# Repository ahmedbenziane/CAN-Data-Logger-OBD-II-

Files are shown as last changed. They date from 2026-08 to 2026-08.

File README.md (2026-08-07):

# Automotive CAN Data Logger & OBD-II Scanner

## Overview
Open-source, dual-mode embedded platform for vehicle data acquisition.
Designed for driver-behaviour analysis, fleet telematics, and CAN bus reverse-engineering.
Works with **any** OBD-II compliant vehicle (active polling) and **any** CAN bus (passive sniffing).
Tested and validated on a production Renault Clio IV.

## Features
- **Active OBD-II polling** – retrieves RPM, speed, coolant temperature, throttle position,
  engine load, and intake air temperature in real time
- **Passive CAN sniffing** – captures every frame on the bus in listen-only mode
- **Proprietary signal reverse-engineering** – mapping of steering angle, wheel speeds,
  and brake pressure (verified against vehicle dynamics)
- **Python live sniffer** – terminal dashboard with per-ID frame count, Hz, and raw bytes;
  optional DBC decoding for immediate signal display
- **SD card logging** – raw frames (binary) and decoded CSV for offline analysis
- **Serial-command marker** – insert timestamped markers during a drive for precise
  event correlation
- **Custom 4-layer PCB** – integrates ESP32-S3, MCP2515 CAN controller, GPS, IMU,
  microSD, USB-C, and automotive power protection

## Repository Structure
```text
├── firmware/   # PlatformIO project (ESP-IDF, FreeRTOS)
├── software/   # Python tools: sniffer, decoder, log extractor, validation plots
├── hardware/   # Altium designer files, BOM, Gerber manufacturing files, schematics PDF
├── docs/       # Additional documentation, signal database, application notes
└── README.md
```

## Getting Started

### Hardware
1. Order the PCB from your favourite manufacturer using the Gerber files in `hardware/Gerber/`.
2. Source the components listed in `hardware/BOM.csv`.
3. Assemble the board (all SMD parts are on the top side; through-hole connectors are hand-soldered).

### Firmware
1. Install [PlatformIO](https://platformio.org/).
2. Open the `firmware/` folder as a PlatformIO project.
3. Select the build environment:
   - `node_a` – **real-car OBD-II polling** (normal mode)
   - `node_a` with `PASSIVE_SNIFF_MODE` – **listen-only CAN capture**
   - `node_b` – **bench simulator** (for testing without a vehicle)
4. Build and upload to the ESP32-S3.

### Software
```bash
pip install -r software/requirements.txt
python software/can_sniffer.py --port 
```

Additional Python tools:

- `decode_log.py` – process candump logs and decode frames with a DBC file
- `extract_can.py` – extract pure CAN frames from serial console logs
- `plot_validation.py` – generate validation plots from OBD-II JSON logs

## Validation
The system has been validated on a Real Car:

- Active OBD-II polling matches dashboard gauges within their resolution
- Passive sniffing captures all broadcast CAN identifiers 
- Proprietary signals (steering, wheel speeds, brake pressure) are decoded and physically verified
- Continuous logging over a 30-minute drive with zero firmware crashes

## Customisation
- Add your own signal definitions by editing  DBC file
- Modify the OBD-II schedule in `decoder_app.c` to poll different PIDs
- Implement on-device inference by deploying a trained model using TensorFlow Lite Micro

## License
This project is released under the MIT License.

## Acknowledgements
- comma-ai/opendbc for open CAN databases
- JLCPCB for PCB fabrication
- The open-source automotive community for reverse-engineering knowledge

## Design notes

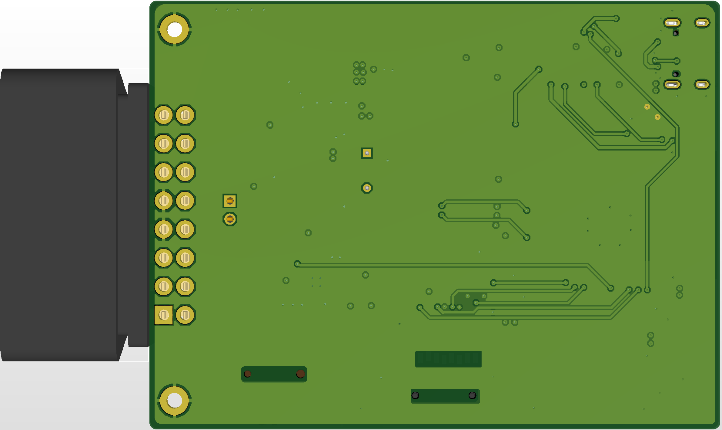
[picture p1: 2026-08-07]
hardware/photos/CAR_Interface_PCB_buttom.png

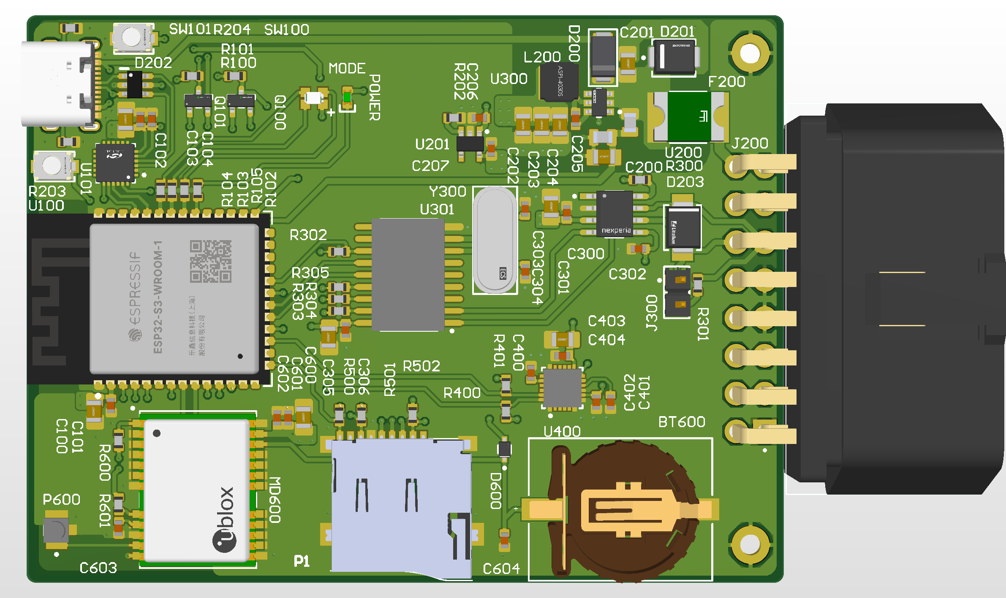
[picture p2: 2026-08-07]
hardware/photos/CAR_Interface_PCB.png

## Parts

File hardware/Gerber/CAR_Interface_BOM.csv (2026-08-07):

Comment | Description | Designator | Footprint | LibRef | Quantity
S8411-45R | BATTERY HOLDER COIN 12MM SMD | BT600 | FP-S8411-45R-MFG | CMP-15817-000007-1 | 1
10u | Capacitor SMD 0805 | C100, C102, C201, C202, C203, C204, C301, C305, C403, C600 | CAP_0805 | CAP_0805 | 10
100n | Capacitor SMD 0603 | C101, C103, C104, C205, C206, C207, C300, C302, C306, C401, C402, C404, C601, C602, C603, C604 | CAP_0603 | CAP_0603 | 16
100n | Capacitor SMD 0805 | C200 | CAP_0805 | CAP_0805 | 1
33pF | Capacitor SMD 0603 | C303, C304 | CAP_0603 | CAP_0603 | 2
2.2nF | Capacitor SMD 0603 | C400 | CAP_0603 | CAP_0603 | 1
D_SCH_SMA | Diode Schottky SMD SMA (DO-214AA) | D200 | DO-214AC-2 (SMA) | D_SCHOTTKY_SMA | 1
SMBJ24A | TVS DIODE 24V 38.9V SMB | D201 | FP-SMBJ-MFG | CMP-07401-000035-1 | 1
USBLC6-2SC6 | Low-Capacitance ESD Protection USB | D202 | SOT-23-6 | USBLC6-2SC6 | 1
P6SMB18CA | TVS DIODE 15.3V 25.5V DO214AA | D203 | FP-P6SMB-CA-MFG | CMP-08607-000095-1 | 1
BAT54J,115 | DIODE SCHOTTKY 30V 200MA SOD323F | D600 | FP-SOD323F-MFG | CMP-14398-000037-1 | 1
2920L050/72GR | PTC RESET FUSE 60V 1.1A 2920 | F200 | FP-2920L-MFG | CMP-08606-000028-1 | 1
C-OBD-II-16M | OBD II 16pin 90 Degree Angle Male Plug Connector | J200 | COMTECH_C-OBD-II-16M | CMP-002-00074-1 | 1
USB4105-GF-A-060 | USB Connector Type C SMT 12 Pin | J201 | USB4105-GF-A-060 | USB4105-GF-A-060 | 1
TSW-102-14-G-S | CONN HEADER VERT 2POS 2.54MM | J300 | FP-TSW-102-14-G-S-MFG | CMP-02766-001740-1 | 1
4.7uH | Power Inductor SMD ASPI-4030S Series | L200 | ASPI-4030S | ASPI-4030S | 1
NEO-M9N-00B | M9 standard precision module | MD600 | FP-NEO-M9N-00B-MFG | CMP-207130-000006-2 | 1
TOGIALED TJ-S2012SW8TWMLCCYRGB-A5 | RGB LED Common Anode SMD Diffused 0805 Top View | MODE | 150080M153000 | 150080M153000 | 1
ST-TF-003A | Micro SD Card Socket | P1 | SUNTECH_ST-TF-003A | CMP-002-00072-2 | 1
U.FL-R-SMT-1(01) | Ultra Small Coaxial Connector, 6 GHz, -40 to 90 degC, 3-Pin SMD, RoHS, Bulk | P600 | HRS-U.FL-R-SMT-3_V | CMP-2000-05153-1 | 1
GREEN | LED 0603 GREEN SMD | POWER | LED_0603_GREEN | LED_0603_GREEN | 1
BSS138 | MOSFET N-CH 50V 220MA SOT-23 | Q100, Q101 | FP-318-08-IPC_B | CMP-07173-000101-1 | 2
10k | Resistor SMD 0603 | R100, R101, R300 | RES_0603 | RES_0603 | 3
620Ohm | Resistor SMD 0603 | R102, R103 | RES_0603 | RES_0603 | 2
360Ohm | Resistor SMD 0603 | R104, R105 | RES_0603 | RES_0603 | 2
100k | Resistor SMD 0805 | R200 | RES_0805 | RES_0805 | 1
10k | Resistor SMD 0805 | R201 | RES_0805 | RES_0805 | 1
5k1 | Resistor SMD 0603 | R202, R203, R204, R302, R303, R304, R305, R400, R401, R500, R501, R502, R600, R601 | RES_0603 | RES_0603 | 14
120Ohm | Resistor SMD 0603 | R301 | RES_0603 | RES_0603 | 1
TL1015AF160QG | SWITCH TACTILE SPST-NO 0.05A 12V | SW100, SW101 | FP-TL1015AF160QG-MFG | CMP-17879-000003-1 | 2
ESP32-S3-WROOM-1-N4 | 2.4 GHz Wi-Fi (802.11 b/g/n) and Bluetooth 5 (LE) Module ESP32-S3, 4MB Flash, on-board PCB antenna) | U100 | ESP32-S3-WROOM-1 | ESP32-S3-WROOM-1-N4 | 1
CP2102N-A02-GQFN24R | IC USB TO UART BRIDGE QFN24 | U101 | FP-CP2102N-A02-GQFN24R-MFG | CMP-08107-000009-2 | 1
AP63205WU-7 | IC REG BUCK 5V 2A TSOT26 | U200 | FP-TSOT26-MFG | CMP-12757-000001-1 | 1
NCP115ASN330T2G | LDO Regulator - High PSRR 300 mA 3.3V TSOP-5 | U201 | TSOT25 | NCP115ASN330T2G | 1
TJA1042T/3/CM,118 | IC TRANSCEIVER HALF 1/1 8SO | U300 | FP-SOT96-1-IPC_A | CMP-10098-000021-1 | 1
MCP2515T-I/SO | Stand-Alone CAN Controller With SPI Interface, 18-Pin SOIC, Industrial Temperature, Tape and Reel | U301 | SOIC-SO18_N | CMP-0186-00139-2 | 1
MPU-6050 | 3-Axis Gyroscope, Accelerometer and a Digital Motion Processor(TM) (DMP), 2.375 to 3.46 V, -40 to 85 degC, 24-Pin QFN, RoHS, Tape and Reel | U400 | IS-QFN-24_V | CMP-1753-00002-2 | 1
ECS-80-20-4X |  | Y300 | FP-ECS-80-20-4X-MFG | CMP-1669-00002-3 | 1

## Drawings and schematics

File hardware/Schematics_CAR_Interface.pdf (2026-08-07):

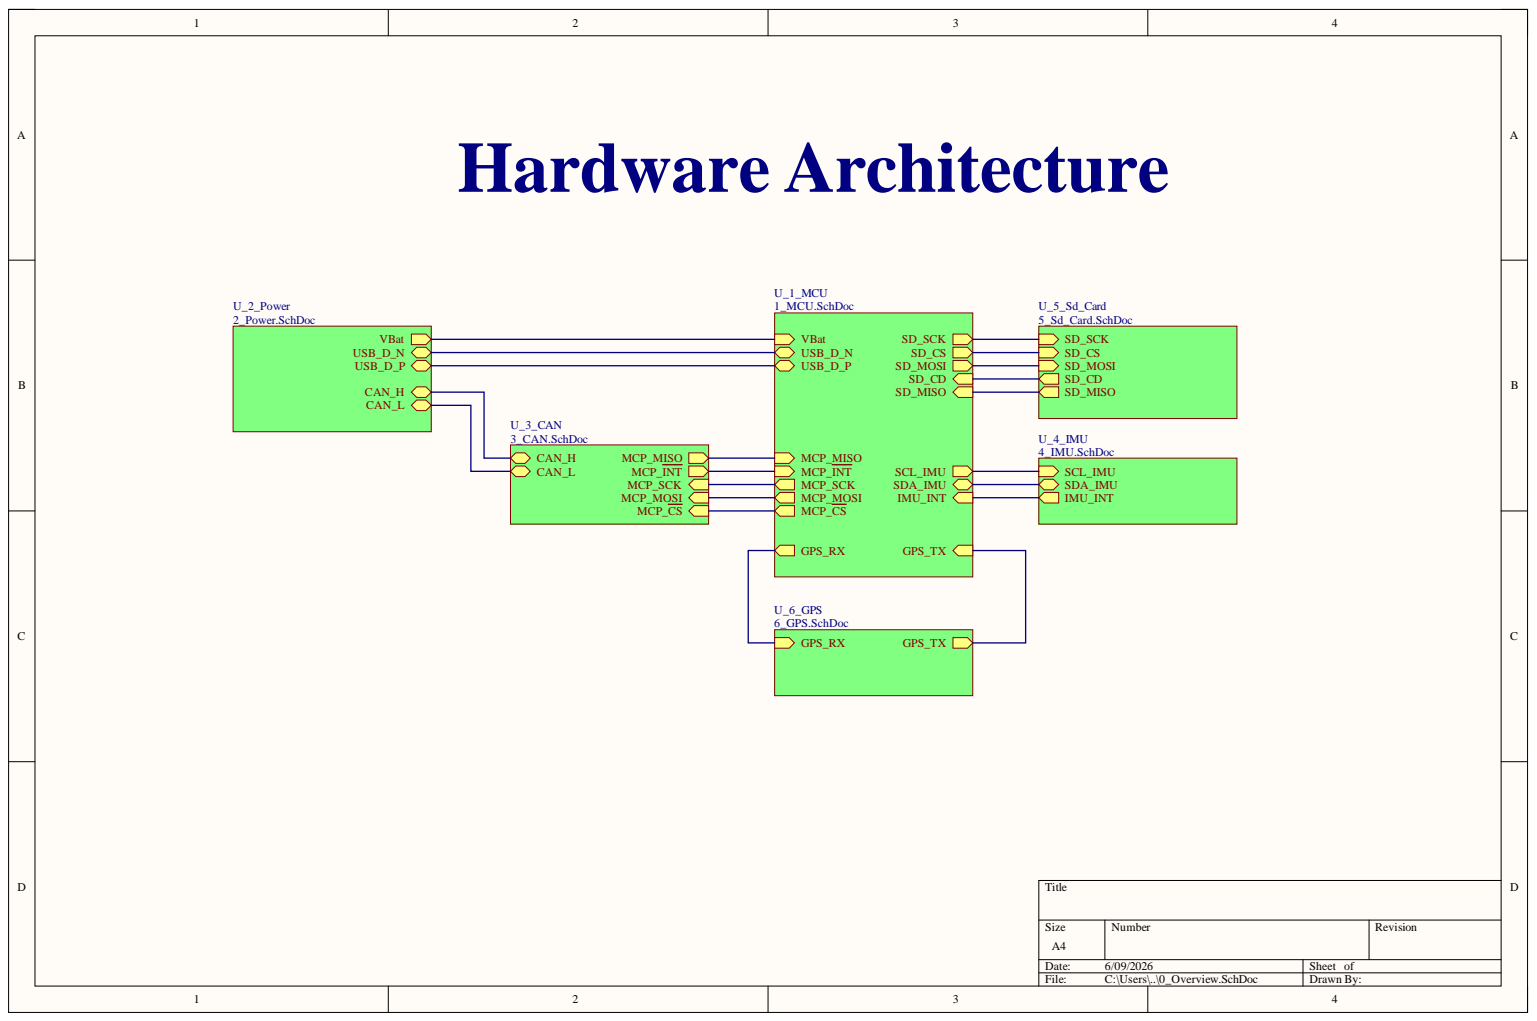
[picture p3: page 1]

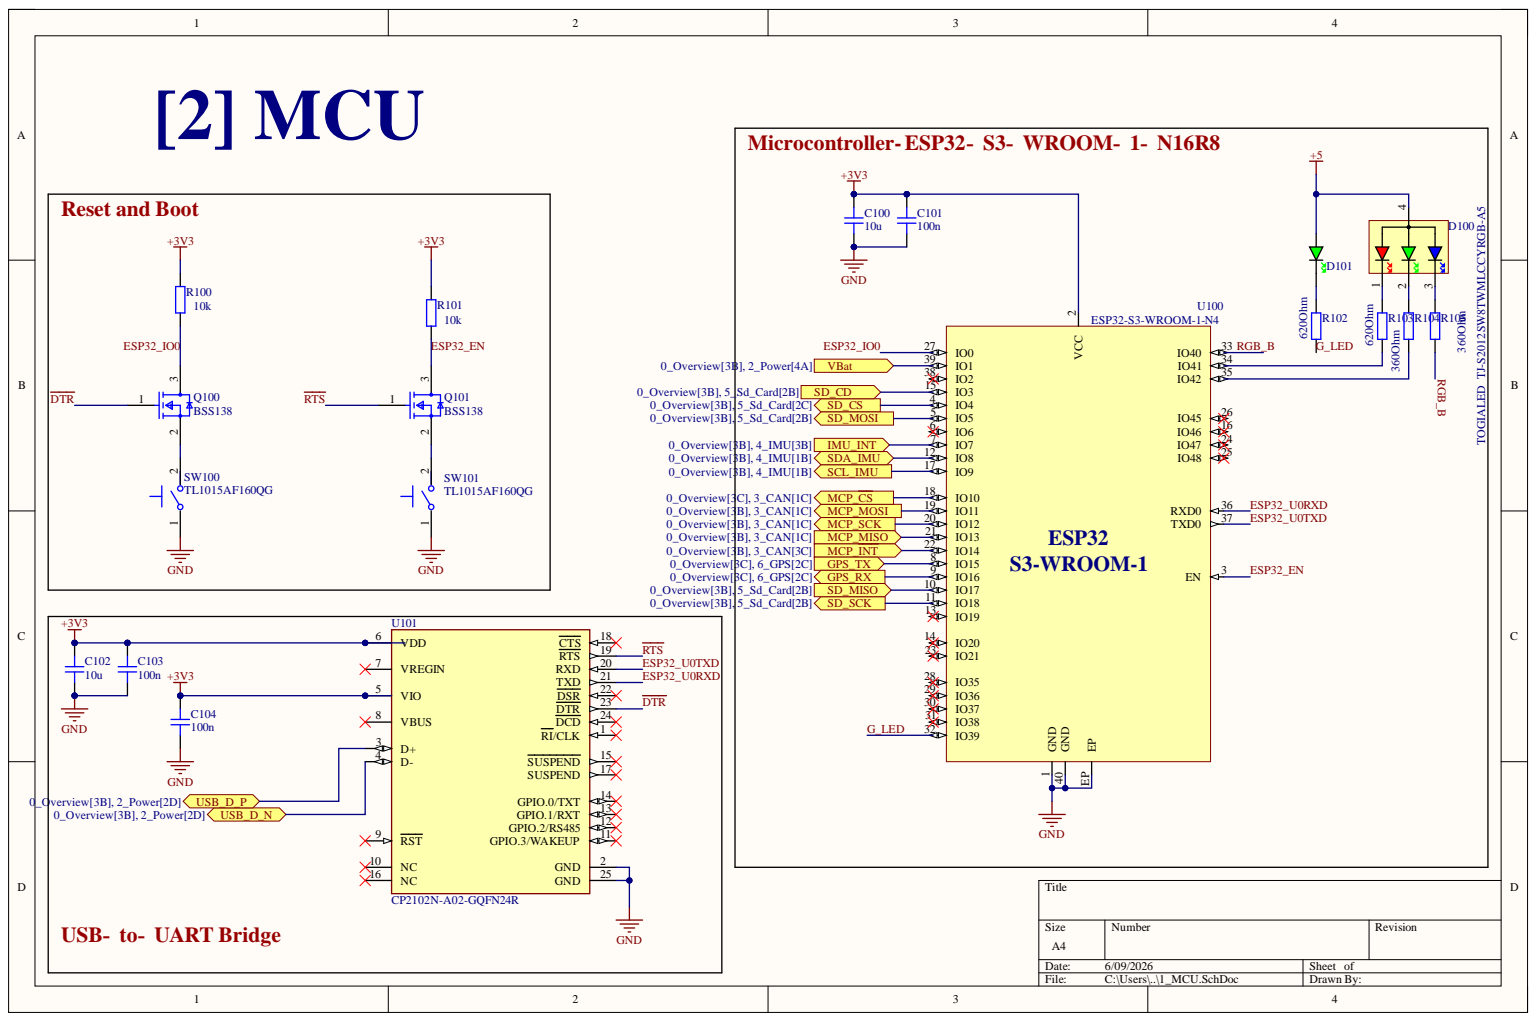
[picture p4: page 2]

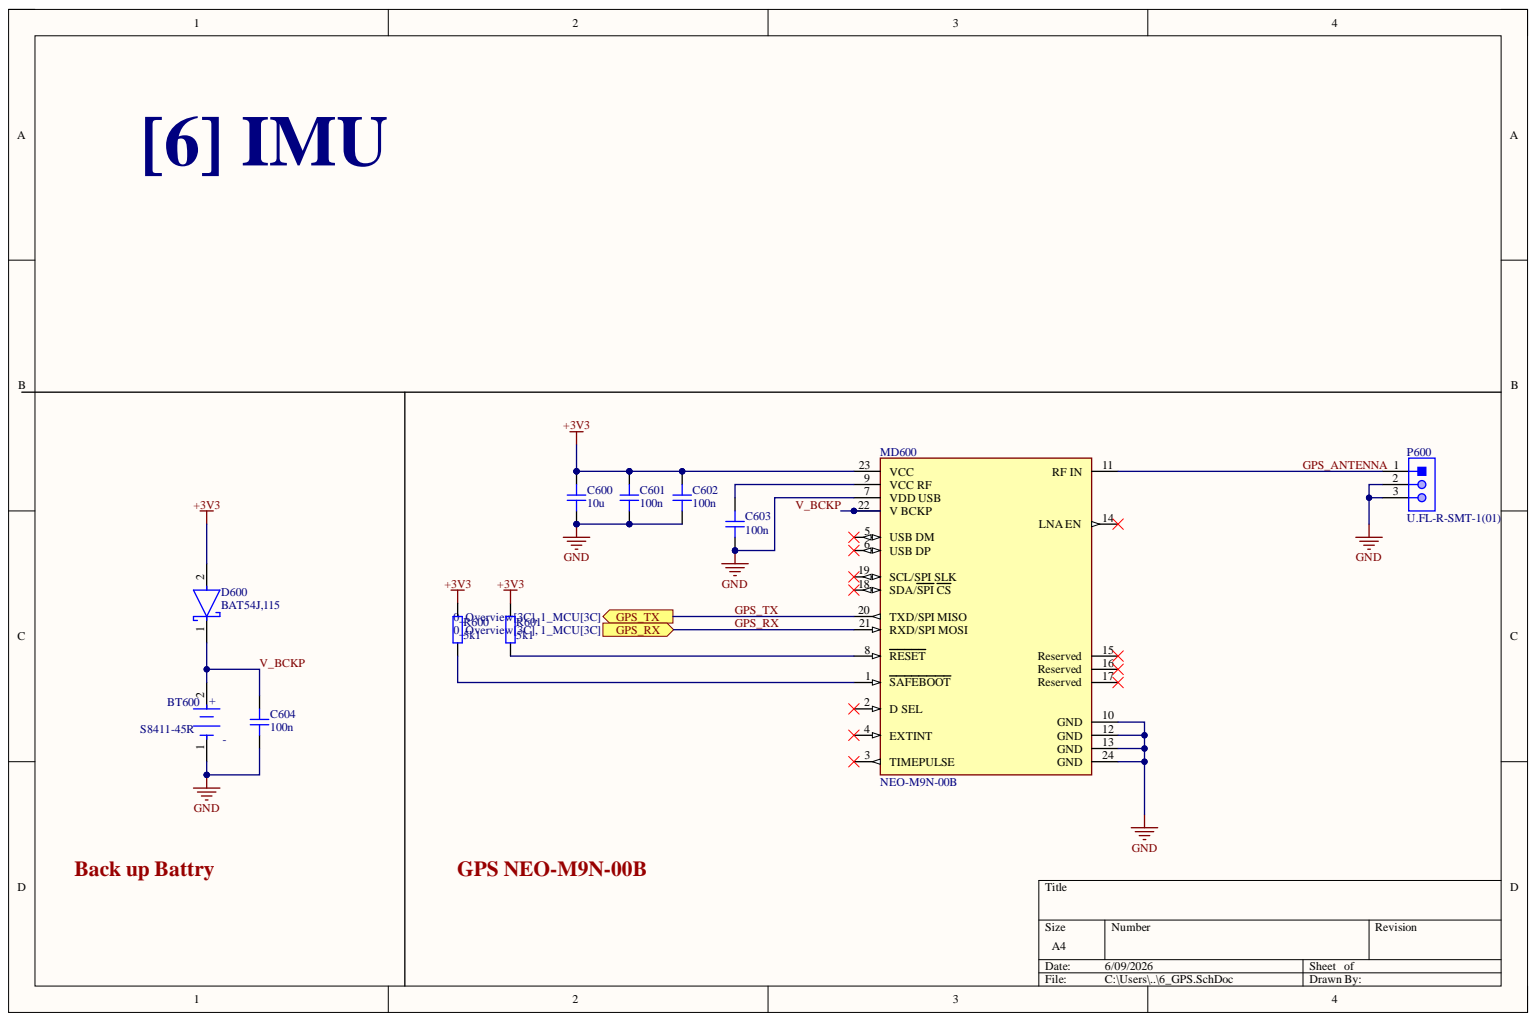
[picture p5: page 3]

V _BCK P C6 0 3 1 0 0 n | 2 2 5

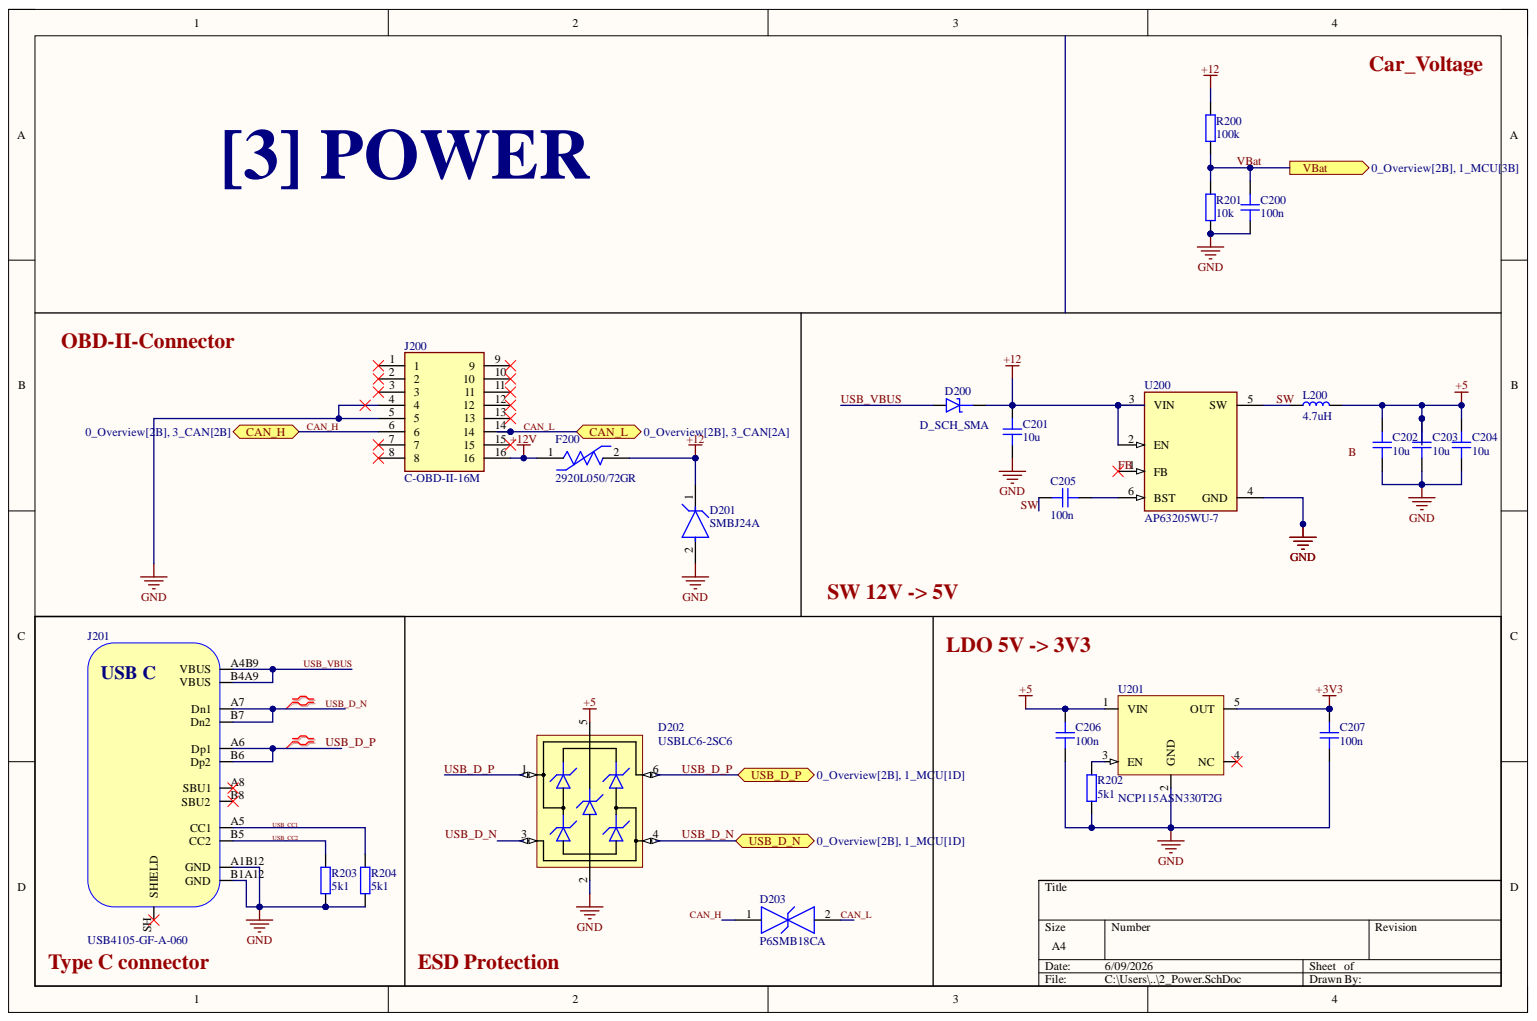
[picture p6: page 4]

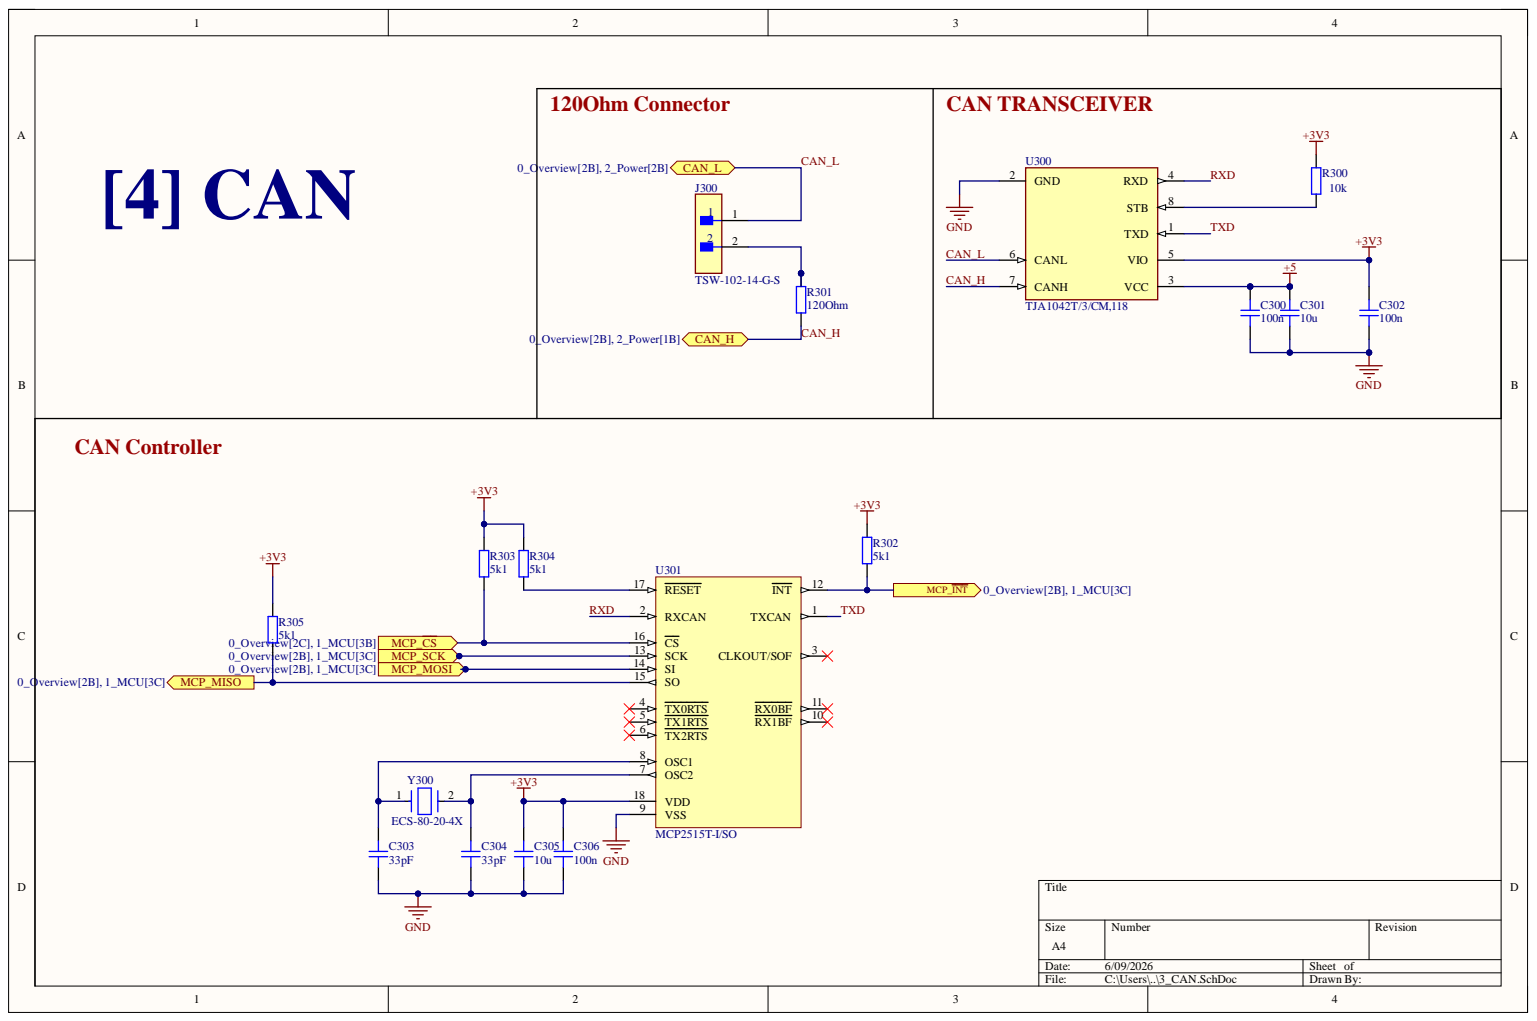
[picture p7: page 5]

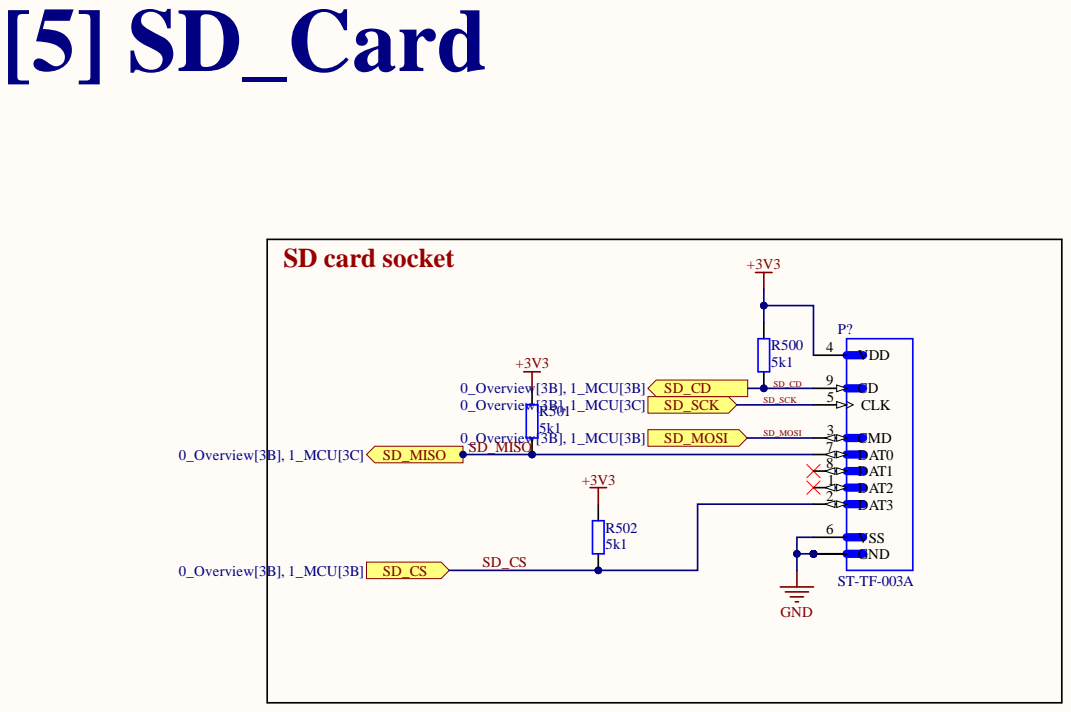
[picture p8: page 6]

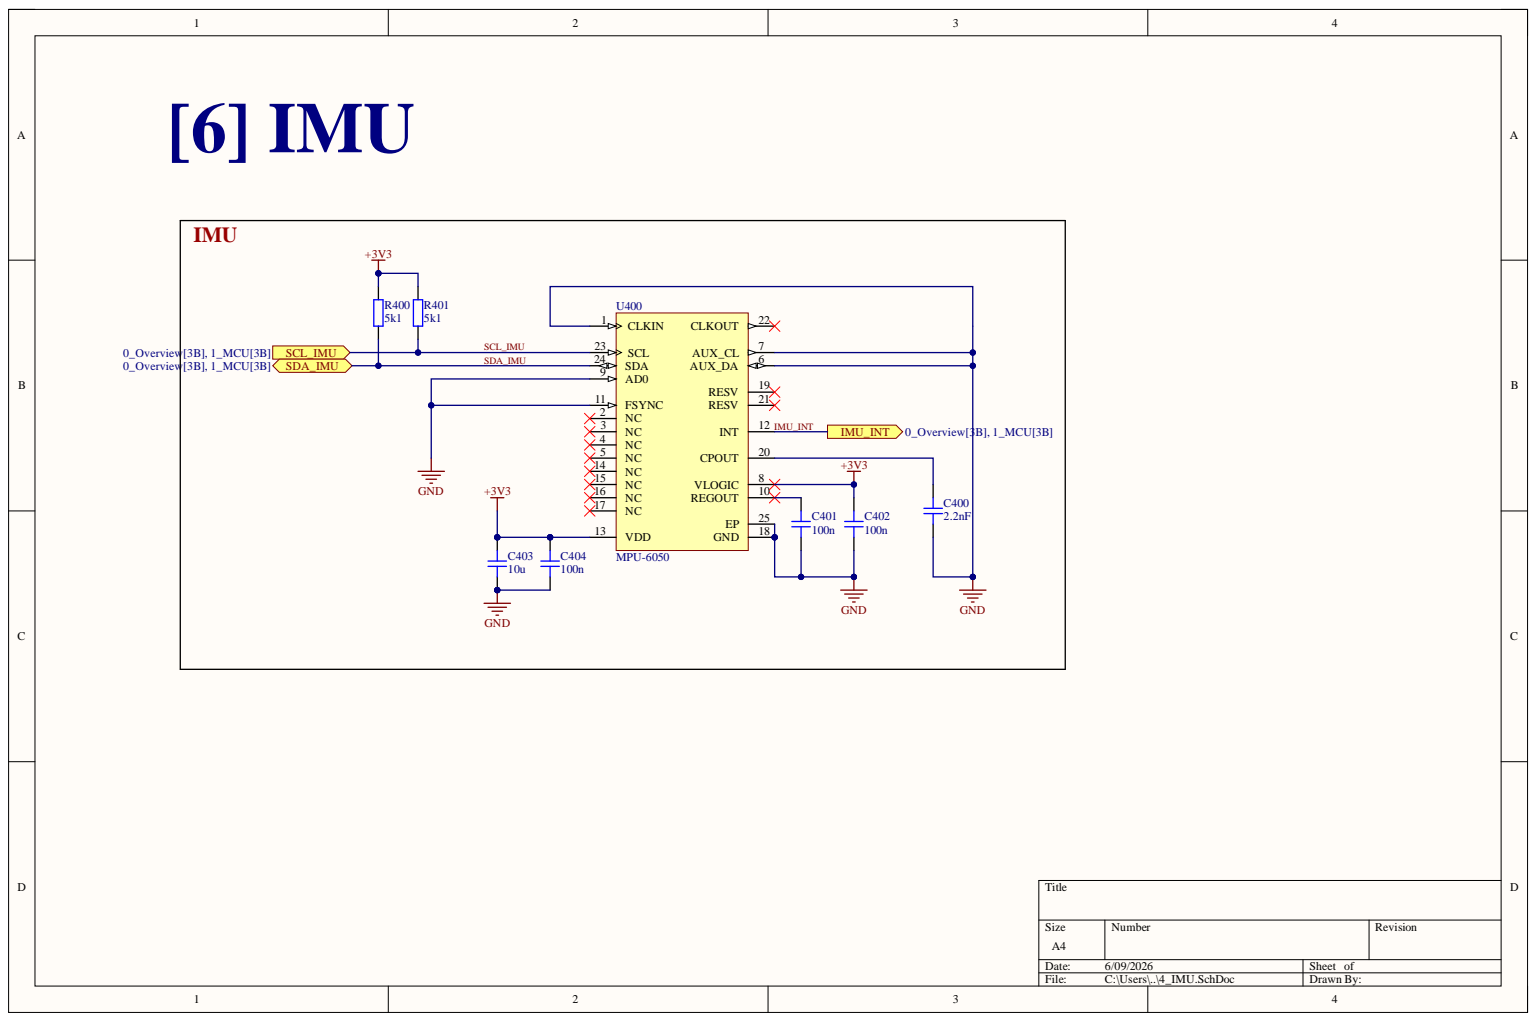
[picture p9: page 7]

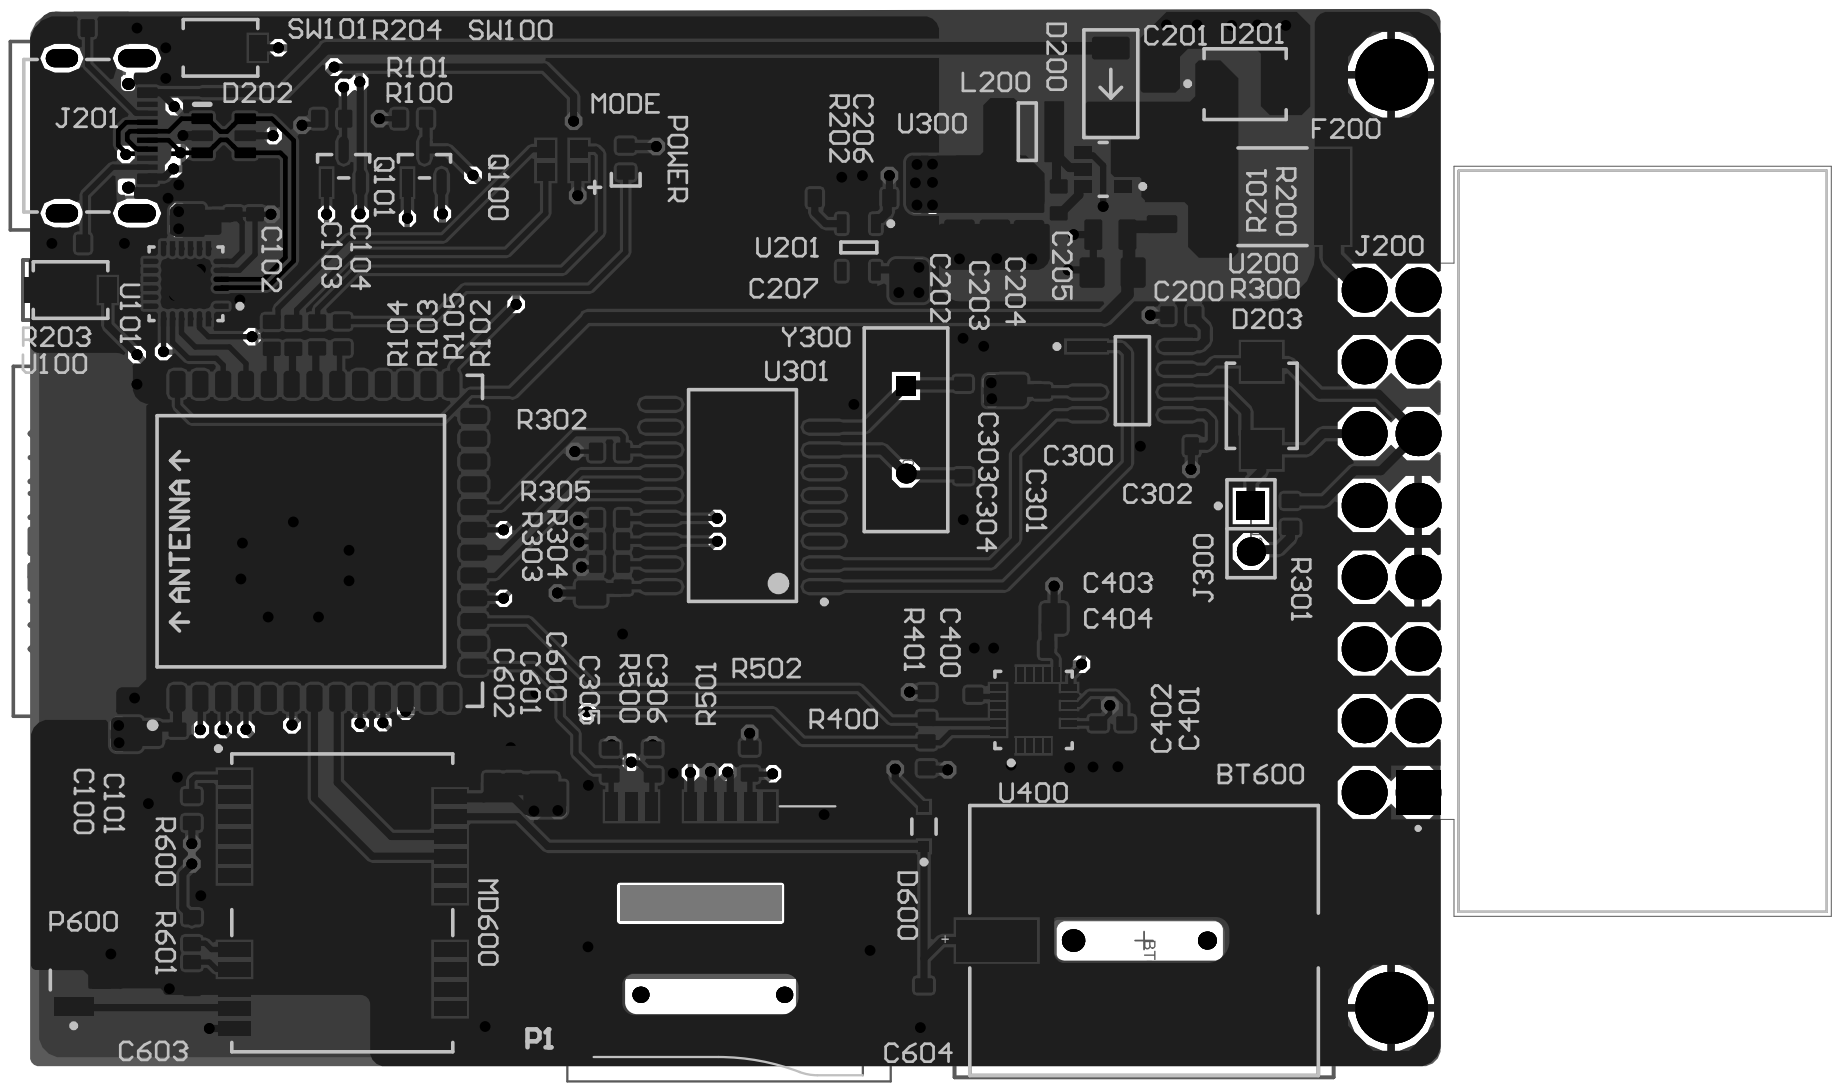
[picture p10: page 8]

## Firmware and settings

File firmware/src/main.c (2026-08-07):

/**
 * @file main.c
 * @brief Step 14 — Real Car (OBD-II Polling) + Bench Test entry point
 *
 * ── Mode selection ─────────────────────────────────────────────────────
 * Controlled entirely from platformio.ini. Never edit this file to
 * switch modes. Two environments exist:
 *
 *   [env:node_a]                     [env:node_a_bench]
 *   build_flags += -DREAL_CAR_MODE   (REAL_CAR_MODE absent)
 *
 * REAL_CAR_MODE absent  → bench mode (NORMAL, UDS test ON, 60 s auto-stop)
 * REAL_CAR_MODE defined → car mode   (NORMAL, OBD-II poller ON, run forever)
 *
 * Both modes use MCP_MODE_NORMAL. Car mode is NOT LISTEN_ONLY — the OBD-II
 * poller MUST transmit query frames to wake the Renault diagnostic CAN bus
 * and receive responses. LISTEN_ONLY silenced the bus on previous attempts.
 *
 * ── Node roles ─────────────────────────────────────────────────────────
 *   NODE_RECEIVER    (Node A) → decoder + SD logger + GPS + shutdown button
 *                                + UDS client (bench) OR OBD engine (car)
 *   NODE_TRANSMITTER (Node B) → multi-ECU bench simulator (unchanged)
 *
 * ── Flash commands ─────────────────────────────────────────────────────
 *   Car:     pio run --target upload --environment node_a
 *   Bench:   pio run --target upload --environment node_a_bench
 *   Node B:  pio run --target buildfs  --environment node_b
 *            pio run --target uploadfs --environment node_b
 *            pio run --target upload   --environment node_b
 */

#include <stdio.h>
#include "freertos/FreeRTOS.h"
#include "freertos/task.h"
#include "esp_log.h"

#include "project_config.h"
#include "mcp2515.h"

#if NODE_ROLE == NODE_TRANSMITTER
#include "ecu_sim_app.h"
#endif

#if NODE_ROLE == NODE_RECEIVER
#include "decoder_app.h"
#include "sd_logger.h"
#include "shutdown_button.h"
/* #include "gps_app.h"   // uncomment once NEO-6M is wired */
#endif

#ifndef NODE_NAME
#define NODE_NAME "Node?"
#endif
static const char *TAG = NODE_NAME;

#define SPIFFS_SYSTEM_JSON "/spiffs/system.json"

#if NODE_ROLE == NODE_TRANSMITTER
static ecu_sim_t s_sim;
#endif

void app_main(void)
{
    /* ── Boot banner ────────────────────────────────────────────────── */
    ESP_LOGI(TAG, "╔══════════════════════════════════════════╗");
#ifdef REAL_CAR_MODE
    ESP_LOGI(TAG, "║  Step 14 — REAL CAR  (OBD-II POLLING)    ║");
#else
    ESP_LOGI(TAG, "║  Step 14 — BENCH     (NORMAL mode)       ║");
#endif
    ESP_LOGI(TAG, "║  Node: %-34s ║", NODE_NAME);
    ESP_LOGI(TAG, "╚══════════════════════════════════════════╝");

    /* MCP2515 crystal stabilisation (500 ms for cold POWERON_RESET). */
    vTaskDelay(pdMS_TO_TICKS(500));

#if NODE_ROLE == NODE_RECEIVER
    /* SD logger first — initialises SPI3_HOST (VSPI) while it is free.
     * SD card  → SPI3_HOST  GPIO 13/27/14/26
     * MCP2515  → SPI2_HOST  GPIO 23/19/18/5  (separate bus)             */
    sd_logger_init();

    /* Shutdown button — GPIO33 jumper-to-GND (no LED, no resistor). */
    shutdown_button_init();
#endif

    /* MCP2515 in CONFIG mode here; decoder_app_start() promotes to NORMAL */
    mcp2515_config_t cfg = {
        .spi_host = MCP2515_SPI_HOST,
        .cs_pin = SPI_CS_PIN,
        .int_pin = MCP2515_INT_PIN,
        .osc_mhz = MCP2515_OSC_MHZ,
        .bitrate_bps = CAN_BITRATE,
        .initial_mode = MCP_MODE_CONFIG,
    };

    esp_err_t init_ret = ESP_FAIL;
    for (int attempt = 1; attempt <= 5; attempt++)
    {
        init_ret = mcp2515_init(&cfg);
        if (init_ret == ESP_OK)
            break;
        ESP_LOGW(TAG, "mcp2515_init attempt %d/5: %s — retrying in 500 ms",
                 attempt, esp_err_to_name(init_ret));
        vTaskDelay(pdMS_TO_TICKS(500));
    }
    if (init_ret != ESP_OK)
    {
        ESP_LOGE(TAG, "mcp2515_init failed after 5 attempts — check SPI wiring");
        for (;;)
            vTaskDelay(pdMS_TO_TICKS(1000));
    }
    ESP_LOGI(TAG, "MCP2515 init OK");

/* ── Node B: bench ECU simulator ───────────────────────────────────── */
#if NODE_ROLE == NODE_TRANSMITTER
    ecu_sim_init(&s_sim);
    ecu_sim_load_config(&s_sim, SPIFFS_SYSTEM_JSON);
    ESP_ERROR_CHECK(ecu_sim_start(&s_sim));
    ESP_LOGI(TAG, "Node B — multi-ECU simulator running");
    ESP_LOGI(TAG, "Streams: 0x7E8/100ms  0x0A6/10ms  0x1A0/10ms  0x3B0/20ms");
    for (;;)
        vTaskDelay(pdMS_TO_TICKS(10000));

/* ── Node A: decoder + logger ──────────────────────────────────────── */
#else
    /* Extra 1 s delay before decoder starts:
     *   Bench: lets Node B start broadcasting before Node A listens.
     *   Car:   harmless — the bus is already live before ESP32 boots. */
    vTaskDelay(pdMS_TO_TICKS(1000));

    /* decoder_app_start() reads REAL_CAR_MODE internally:
     *   defined   → NORMAL + dispatcher(0x7E8 → OBD engine) + obd_poller_task
     *   undefined → NORMAL + dispatcher(0x7E8/0xA6/0x1A0/0x3B0) + uds_test_task */
    ESP_ERROR_CHECK(decoder_app_start());

#ifdef REAL_CAR_MODE
    ESP_LOGI(TAG, "Node A — OBD-II active poller (car mode)");
    ESP_LOGI(TAG, "Wiring: OBD pin6=CAN-H  pin14=CAN-L  pin4=GND(ESP32)");
    ESP_LOGI(TAG, "Power:  USB power bank recommended over laptop USB");
    ESP_LOGI(TAG, "Stop:   touch GPIO%d jumper to GND before ignition off",
             SHUTDOWN_BUTTON_GPIO);
    for (;;)
        vTaskDelay(pdMS_TO_TICKS(10000));

#else
    /* Bench: auto-shutdown after 60 s. */
    ESP_LOGI(TAG, "Node A — decoder + UDS test client (bench mode)");
    ESP_LOGI(TAG, "Auto-shutdown in 60 s");
    ESP_LOGI(TAG, "Wait for '✓ SD card safely unmounted' before removing card");
    vTaskDelay(pdMS_TO_TICKS(60000));
    ESP_LOGI(TAG, "Auto-shutdown: flushing SD...");
    sd_logger_deinit();
    ESP_LOGI(TAG, "✓ SD card safe to remove. Halted.");
    for (;;)
        vTaskDelay(pdMS_TO_TICKS(1000));
#endif

#endif /* NODE_ROLE */
}

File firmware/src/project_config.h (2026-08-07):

#pragma once

/* ============================================================
 *  project_config.h
 *  Central configuration header — included by every component.
 *  All values come from platformio.ini build_flags.
 *  NEVER hardcode pins or roles anywhere else.
 * ============================================================ */

#include <stdint.h>
#include <stdbool.h>
#include "driver/spi_master.h"
#include "driver/uart.h"

/* ── Node Role ────────────────────────────────────────────── */
#define NODE_TRANSMITTER 0 /* Node A: diagnostic tester     */
#define NODE_RECEIVER 1    /* Node B: ECU simulator/sniffer */

/* NODE_ROLE is injected by platformio.ini -DNODE_ROLE=...     */
#ifndef NODE_ROLE
#error "NODE_ROLE not defined. Use -DNODE_ROLE in platformio.ini"
#endif

/* ── SPI / MCP2515 Hardware ───────────────────────────────── */
/* All pins injected by platformio.ini                         */
#ifndef SPI_MOSI_PIN
#define SPI_MOSI_PIN 23
#endif
#ifndef SPI_MISO_PIN
#define SPI_MISO_PIN 19
#endif
#ifndef SPI_SCK_PIN
#define SPI_SCK_PIN 18
#endif
#ifndef SPI_CS_PIN
#define SPI_CS_PIN 5
#endif
#ifndef MCP2515_INT_PIN
#define MCP2515_INT_PIN 4
#endif

/* SPI clock — keep at or below 8 MHz for reliable MCP2515 comms */
#define SPI_CLOCK_HZ (8 * 1000 * 1000)
#if defined(HSPI_HOST)
#define MCP2515_SPI_HOST HSPI_HOST
#elif defined(SPI2_HOST)
#define MCP2515_SPI_HOST SPI2_HOST
#else
#error "No compatible SPI host found for MCP2515"
#endif
#define SPI_DMA_CHANNEL 1

/* ── CAN Bus Parameters ───────────────────────────────────── */
#ifndef CAN_BITRATE
#define CAN_BITRATE 500000 /* 500 kbps — ISO 15765-4     */
#endif
#ifndef MCP2515_OSC_MHZ
#define MCP2515_OSC_MHZ 8 /* Crystal MHz on MCP2515 PCB */
#endif

/* ── Ring Buffer ──────────────────────────────────────────── */
#define CAN_RX_RING_SIZE 256 /* Must be power of 2          */
#define CAN_TX_QUEUE_SIZE 16

/* ── FreeRTOS Task Config ─────────────────────────────────── */
#define TASK_STACK_CAN_RX 4096
#define TASK_STACK_CAN_TX 2048
#define TASK_STACK_APP 8192

#define TASK_PRIO_CAN_RX 15 /* Highest — ISR-driven        */
#define TASK_PRIO_CAN_TX 14
#define TASK_PRIO_APP 5

#define TASK_CORE_CAN 0 /* Core 0: all CAN I/O         */
#define TASK_CORE_APP 1 /* Core 1: processing + app    */

/* ── Logging ──────────────────────────────────────────────── */
#define CAN_LOG_UART_NUM UART_NUM_0
#define CAN_LOG_BAUD 115200

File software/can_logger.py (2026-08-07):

#!/usr/bin/env python3
"""
can_logger.py  —  CAN + GPS session capture / full simulation mode

Usage:
  pip install pyserial
  python can_logger.py --port COM12 --baud 115200       # real Node A
  python can_logger.py --simulate                        # full fake session
  python can_logger.py --port COM12 --baud 115200 --inject-gps  # real CAN + fake GPS
"""

import argparse, csv, datetime, json, math, os, sys, time, threading, random
try:
    import serial
    HAS_SERIAL = True
except ImportError:
    HAS_SERIAL = False

WHEELBASE_M  = 2.6
STEER_RATIO  = 14.0

stats = dict(total=0, dec=0, gps=0, uds=0, errors=0, started=time.time())

# ── Real Algiers road waypoints ──────────────────────────────────────────
# Route: Hydra → Bir Mourad Raïs → Ruisseau → back
# Each entry: (lat, lon, heading_deg, speed_kmh, brake_bar)
ALGERIA_ROUTE = [
    (36.737200, 3.086900,  45, 30,  0),
    (36.738100, 3.088200,  52, 35,  0),
    (36.739400, 3.090100,  48, 40,  0),
    (36.740200, 3.092000,  55, 45,  0),
    (36.741000, 3.094300,  60, 50,  2),
    (36.742100, 3.096800,  45, 55,  0),
    (36.743500, 3.098500,  35, 50,  0),
    (36.745000, 3.099600,  15, 45,  5),  # slight brake at junction
    (36.746800, 3.100200,   5, 40,  0),
    (36.748500, 3.100500, 355, 45,  0),
    (36.750000, 3.100100, 345, 50,  0),
    (36.751200, 3.099000, 330, 55,  0),
    (36.752000, 3.097500, 315, 50,  8),  # brake: roundabout
    (36.752500, 3.095800, 300, 35,  0),
    (36.752300, 3.093500, 270, 40,  0),
    (36.751800, 3.091200, 265, 45,  0),
    (36.751000, 3.089100, 255, 50,  0),
    (36.750000, 3.087200, 240, 55,  0),
    (36.748500, 3.085600, 225, 50,  3),
    (36.746800, 3.084200, 220, 45,  0),
    (36.745000, 3.083000, 215, 40,  0),
    (36.743200, 3.082100, 210, 35,  0),
    (36.741500, 3.081500, 200, 30, 10),  # brake: traffic light
    (36.739800, 3.081800, 185, 25,  0),
    (36.738200, 3.082800, 170, 30,  0),
    (36.737200, 3.084200, 145, 35,  0),
    (36.737200, 3.086900,  90, 20, 15),  # arrive back, slow + brake
]

UDS_DIDS = [
    ('0xF190', 'VF14SR6B4FD018433', 28, False),
    ('0xF189', None,                10, False),   # SW version: bytes
    ('0xF18C', 'ECU0123456789',     30, False),
    ('0xF186', '8201312983237R',    35, False),
    ('0xF18E', None,                12, False),   # diag ver: byte
]


# ── Dead reckoning ───────────────────────────────────────────────────────
class DeadReckoning:
    def __init__(self):
        self.x=0.0; self.y=0.0; self.hdg=0.0; self.spd=0.0
        self.last_t=None; self.origin_lat=None; self.origin_lon=None

    def _ll_xy(self, lat, lon):
        R=6_371_000.0
        dlat=(lat-self.origin_lat)*math.pi/180
        dlon=(lon-self.origin_lon)*math.pi/180
        avg=((lat+self.origin_lat)/2)*math.pi/180
        return dlon*R*math.cos(avg), -dlat*R

    def update_gps(self, msg):
        lat,lon,t=msg['lat'],msg['lon'],msg['t']
        if self.origin_lat is None:
            self.origin_lat,self.origin_lon=lat,lon
            self.hdg=msg.get('hdg',0); self.spd=msg.get('spd',0); self.last_t=t
            return None
        x,y=self._ll_xy(lat,lon)
        self.x,self.y=x,y; self.hdg=msg.get('hdg',self.hdg)
        self.spd=msg.get('spd',self.spd); self.last_t=t
        return (t,x,y,self.hdg,self.spd,'GPS')

    def update_can(self, msg):
        if self.last_t is None or self.origin_lat is None: return None
        t=msg['t']; dt=(t-self.last_t)/1000.0
        if dt<=0 or dt>2: self.last_t=t; return None
        wh=msg.get('wh',[0,0,0,0]); spd=sum(wh)/max(len(wh),1)
        steer=msg.get('st',0)/10.0; sms=spd/3.6
        wa=(steer/STEER_RATIO)*math.pi/180; dth=0.0
        if abs(wa)>0.001: dth=(sms*dt)/(WHEELBASE_M/math.tan(wa))
        self.hdg=(self.hdg+math.degrees(dth)+360)%360
        hr=self.hdg*math.pi/180; d=sms*dt
        self.x+=d*math.sin(hr); self.y+=d*math.cos(hr)
        self.spd=spd; self.last_t=t
        return (t,self.x,self.y,self.hdg,self.spd,'DR')


def _stat_printer():
    while True:
        time.sleep(5)
        e=time.time()-stats['started']
        print(f"\r  [{e:5.0f}s] msgs={stats['total']:6d}  "
              f"dec={stats['dec']:5d}  gps={stats['gps']:4d}  "
              f"uds={stats['uds']:3d}  err={stats['errors']:3d}  "
              f"rate={stats['total']/max(e,1):.0f}/s   ",end='',flush=True)


def _open_session(outdir):
    ts=datetime.datetime.now().strftime('%Y%m%d_%H%M%S')
    session=os.path.join(outdir,f'session_{ts}')
    os.makedirs(session,exist_ok=True)

    raw_f=open(os.path.join(session,'raw.jsonl'),'w',buffering=1)

    dec_f=open(os.path.join(session,'decoded.csv'),'w',newline='')
    dec_w=csv.writer(dec_f)
    dec_w.writerow(['timestamp_ms','rpm','steer_deg_x10',
                    'wfl','wfr','wrl','wrr','brake_bar','valid_mask'])

    gps_f=open(os.path.join(session,'gps.csv'),'w',newline='')
    gps_w=csv.writer(gps_f)
    gps_w.writerow(['timestamp_ms','lat','lon','speed_kmh',
                    'heading_deg','altitude_m','satellites','hdop'])

    uds_f=open(os.path.join(session,'uds.csv'),'w',newline='')
    uds_w=csv.writer(uds_f)
    uds_w.writerow(['timestamp_ms','did','elapsed_ms',
                    'length','corrupt','data_hex','ascii'])

    dr_f=open(os.path.join(session,'dead_reckoning.csv'),'w',newline='')
    dr_w=csv.writer(dr_f)
    dr_w.writerow(['timestamp_ms','x_m','y_m','heading_deg','speed_kmh','source'])

    return session,(raw_f,dec_f,gps_f,uds_f,dr_f),(dec_w,gps_w,uds_w,dr_w)


def _write_msg(msg, files, writers, dr):
    raw_f,dec_f,gps_f,uds_f,dr_f = files
    dec_w,gps_w,uds_w,dr_w       = writers
    t = msg.get('type','')
    stats['total'] += 1

    raw_f.write(json.dumps(msg)+'\n')

    if t=='dec':
        stats['dec']+=1
        dec_w.writerow([msg.get('t',0),msg.get('rpm',0),msg.get('st',0),
            *msg.get('wh',[0,0,0,0]),msg.get('br',0),msg.get('vm',0)])
        dec_f.flush()
        row=dr.update_can(msg)
        if row: dr_w.writerow([f'{v:.3f}' if isinstance(v,float) else v for v in row]); dr_f.flush()

    elif t=='dr':
        # ESP32 already computed dead reckoning — just save it directly
        dr_w.writerow([msg.get('t',0),
            f"{msg.get('x',0):.3f}", f"{msg.get('y',0):.3f}",
            f"{msg.get('hdg',0):.1f}", f"{msg.get('spd',0):.1f}",
            msg.get('gc',0)])
        dr_f.flush()

    elif t=='gps':
        stats['gps']+=1
        gps_w.writerow([msg.get('t',0),msg.get('lat',0),msg.get('lon',0),
            msg.get('spd',0),msg.get('hdg',0),msg.get('alt',0),
            msg.get('sat',0),msg.get('hdop',0)])
        gps_f.flush()
        row=dr.update_gps(msg)
        if row: dr_w.writerow([f'{v:.3f}' if isinstance(v,float) else v for v in row]); dr_f.flush()

    elif t=='uds':
        stats['uds']+=1
        uds_w.writerow([msg.get('t',0),msg.get('did',''),msg.get('ms',0),
            msg.get('len',0),msg.get('corrupt',False),msg.get('d',''),msg.get('ascii','')])
        uds_f.flush()
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
